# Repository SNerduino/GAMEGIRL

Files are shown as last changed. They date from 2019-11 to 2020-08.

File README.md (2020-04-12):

# GAMEGIRL
## Introduction
A very simple Game console for girls based on arduino Nano.

The console features :
- 4 color buttons with 4 color leds
- A 16X2 LCD screen for displaying menu and game information
- A Buzzer for music
- An On/Off switch
- A 9V battery as power source

For this version, the console has the form of a heat. I created it for my little daughter. Feel free to rebuild it with your own form and code your own games.

The console has a game registration mechanism, a Highscore saving in EEPROM, and integrates my RTTTL Music playing library (that you can find in my other repository) with the possibility of multitasking led animation (using PMW) with button reading screen updates and audio playing.

## GAMEGIRL RECIPE
### General recipe
To build a GAMEGIRL, you need :
- A shell (be creative)
- Buttons
- LEDS
- An arduino board (we prefer using the little ones like the arduino nano)
- An i2C LCD screen (can be graphical or just character based, it depends on the kind of games you are building)
- A Buzzer to make some noise
- A 9V battery + 9V battery connector + A On/Off switch
- Wires (Lot of wires)
- Software to pilot all of this

## GAMEGIRL V 1.0 recipe
GAMEGIRL V1.0 is a simple leds/buttons game with 4leds and 4buttons as well as an alphanumeric 16X2 screen to show score, live and stuff as well as select games and view highscores.

To build it, here is what you need to do:
0. 3D print the parts froml the STL files
1. Use a hot glue to glue the i2C LCD screen inside the heart position
2. Insert the buttons and the leds in the holes (maybe you need to use a solder tool to widen the holes if the leds don't fit). The pattern is from left to right : red, yellow, green, blue.
3. Connect all ground legs of the buttons together as well as the cathodes of the leds and add a 250Ohms resistor before the ground.  
4. Glue the Arduino nano at the upper-right side of the heart
5. Solder all leds and buttons to the arduino nano pins D2 to D9:
    1. D2 -> red button
    2. D3 -> red led
    3. D4 -> yellow button
    4. D5 -> yellow led
    5. D6 -> green button
    6. D7 -> green led
    7. D8 -> blue button
    8. D9 -> blue led
6. Solder the ground to the arduino ground
7. Connect the arduino SDA/SCL (A4/A5) of I2C to the corresponding pins on the I2C LCD.
8. Connect Vcc pin of the 9V battery connector to the VIN pin of the arduino nano.
9. Connect the GND pin of the 9V battery connector to the GNG pin of the arduino nano.
10. Cut the VCC line of the barrery wire and solder the ON/OFF Switch.
11. Glue the buzzer to the top right part of the heart.
12. Solder one of the buzzer legs to the D11 pin and the other one to the GND. You may want to add a potentiometer between the leg and ground to control volume.

13. Glue the back model to the bottom part of the shell after passing the battery connector inside.
14. Connect the battery.
15. Glue the bottom part of the shell with the top part.
16. Be free to stick decorations on the console.
17. Connect the USB connector to the console
18. Use Arduino IDE to load the code GAME_GIRL.ino to the arduino nano.
19. Have fun and try to maximize your scores.

## Some photos
Here are different components installed into the top part of the console:

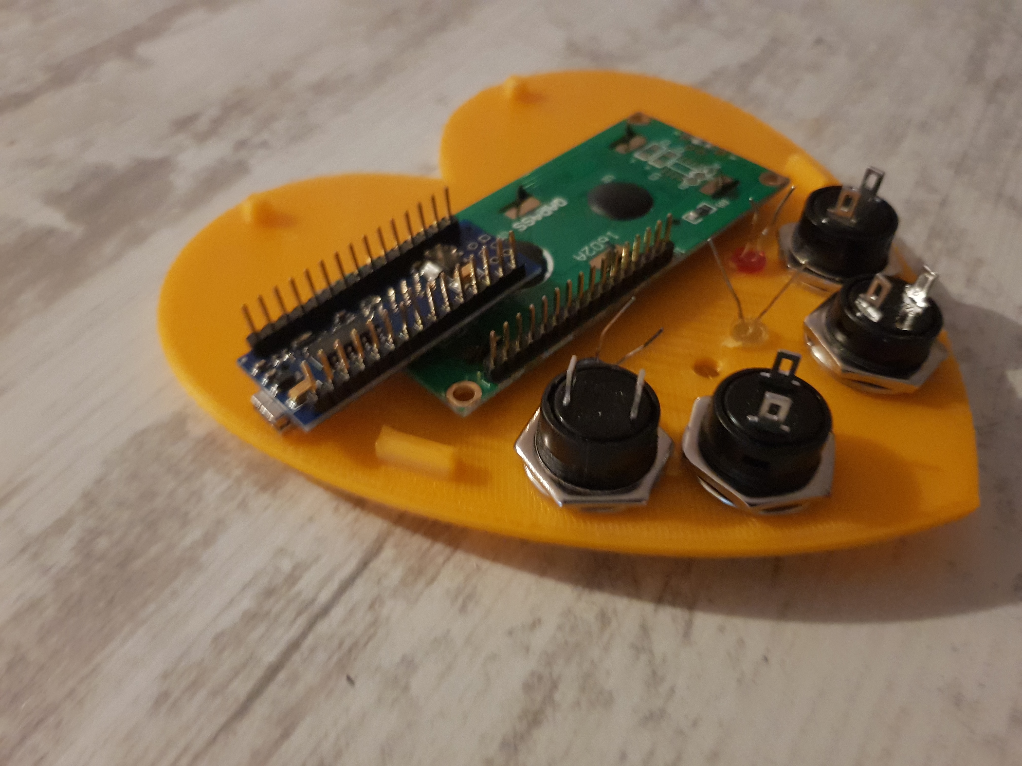
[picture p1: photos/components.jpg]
back

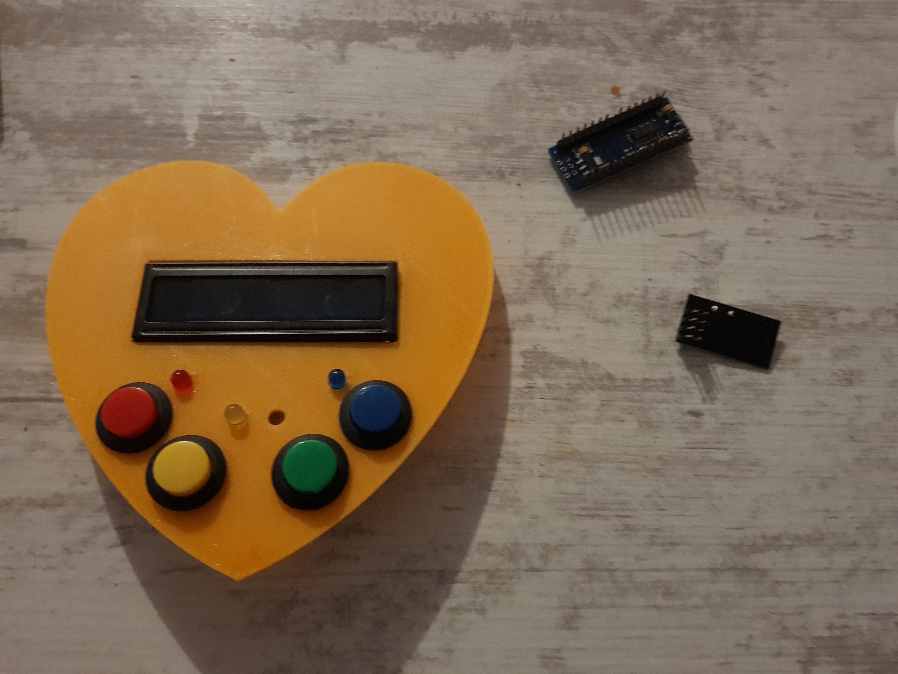
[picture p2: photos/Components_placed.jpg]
front


And here is the final product:

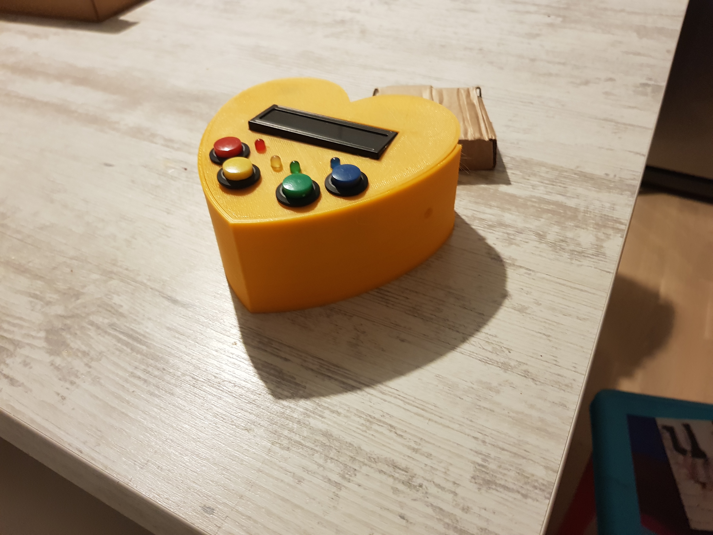
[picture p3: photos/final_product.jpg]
final product


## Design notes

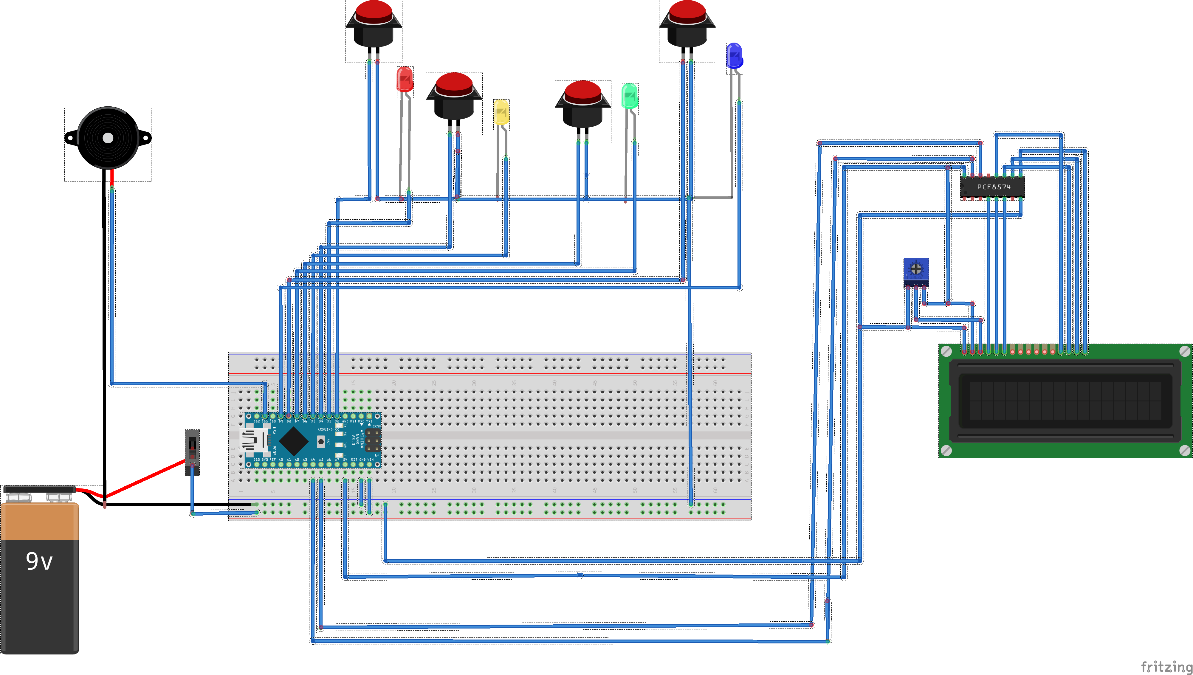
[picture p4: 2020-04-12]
Scheme/GameGirl_bb.png

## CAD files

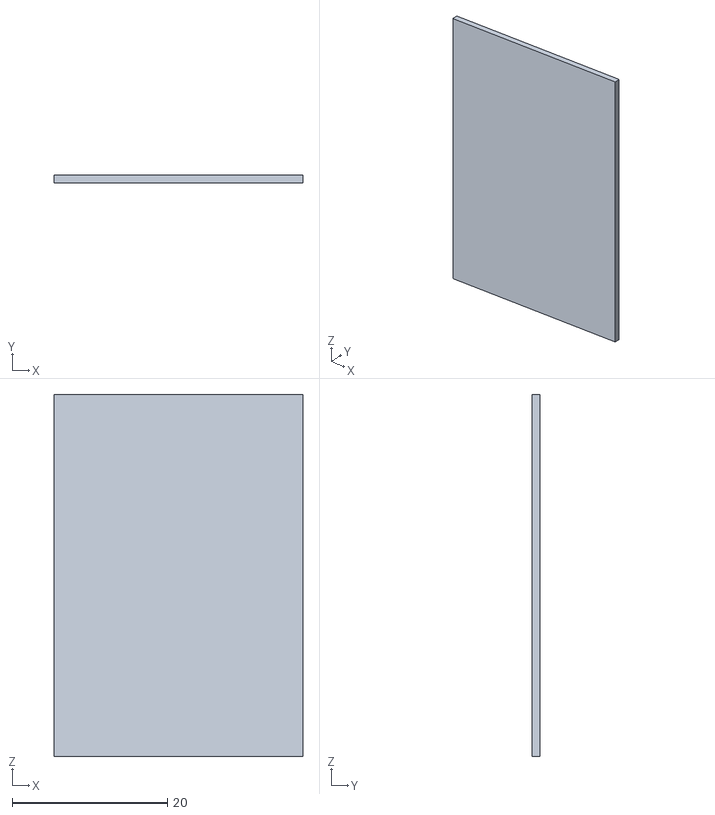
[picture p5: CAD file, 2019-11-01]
Mecanic/Back.stl
32.0 x 1.00 x 46.6

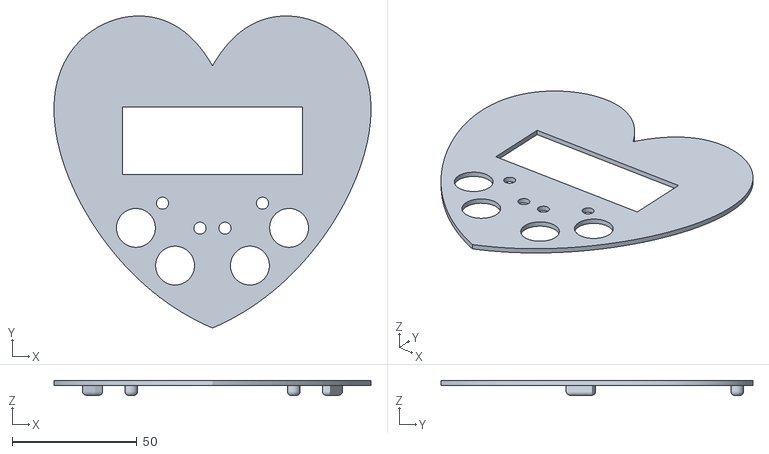
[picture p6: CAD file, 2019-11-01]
Mecanic/Boitier_Top.stl
127.0 x 125.0 x 6.00

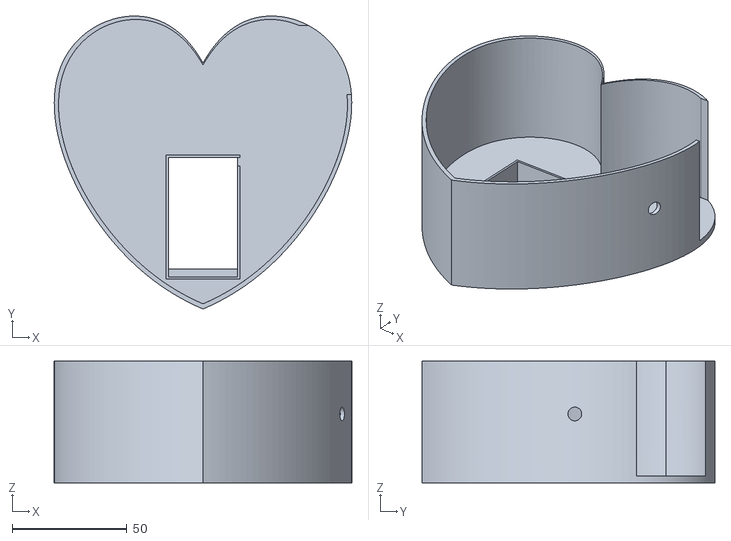
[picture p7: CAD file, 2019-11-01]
Mecanic/Boitier_Bottom.stl
129.5 x 127.5 x 53.0

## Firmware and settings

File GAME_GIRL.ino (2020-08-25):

// GAMEGIRL
// Author: Saifeddine ALOUI AKA SNetuino
// With the help from Line ALOUI

// Import libraries
#include <RTTTL.h>
#include <Wire.h>
#include <LiquidCrystal_I2C.h>
#include <EEPROM.h>

// ===========================
// Defines
// ===========================
// prepare software
#if defined(ARDUINO) && ARDUINO >= 100
#define printByte(args)  write(args);
#else
#define printByte(args)  print(args,BYTE);
#endif
#define NB_MAX_HIGH_SCORES 5


// ===========================
// Enums
// ===========================

// Game parameters
typedef enum {
  status_menu,
  status_playing,
  status_gameover
} System_Status;


// ===========================
// Structures
// ===========================
struct Game { // Every game has an instance from this structure that defines the game name and the function to call to launch the game
  char* name;
  void (*fn)(void);
};

struct ScoreInfo { // Score information (each highscore is composed of the value of the score and the name (3 chars + 0)
  int score;
  char name[4];
};

struct HighScores { // This structure will be flashed to the EEPROM to save high scores
  int hash;
  ScoreInfo scores[NB_MAX_HIGH_SCORES]; //
};

// ===========================
// global variables
// ===========================
// *** High scores ***
int eeAddress = 0; // Address to put highscore data on the EEPROM
HighScores highScores; // highscores structure to save on the EEPROM

// *** Games definition ***
// Games functions prototypes
void reflex_tester(); // A game to test reflexes
void color_memory(); // A game to test capacity to memorize colors sequences
void play_intro(); // Plays intro song
void sticks(); // A sticks removal game
void display_highscores(); // A code to show the savced highscores

Game games[] = { // Here we define games. Add your own games
  {.name = "Reaction test", .fn = reflex_tester},
  {.name = "Color memory", .fn = color_memory},
  {.name = "Sticks", .fn = sticks},
  {.name = "Play Song", .fn = play_intro},
  {.name = "High scores", .fn = display_highscores}
};
int nb_games = sizeof(games) / sizeof(Game); // Computes the number of games
int game_id = 0; // Currently selected game index
int high_score_id = 0; // Current high score index

// *** Global gaming status ***
System_Status system_status = status_menu; // 0 => Menu, 1=> Playing, 2=> Game over

// *** Hardware variables ***
// Prepare liquid crystal
LiquidCrystal_I2C lcd(0x27, 16, 2); // set the LCD address to 0x27 for a 16 chars and 2 line display_infos
// Define a heart needed to show how many lives left
uint8_t heart[8] = {0x0, 0xa, 0x1f, 0x1f, 0xe, 0x4, 0x0};

// -- Pins --
// Buttons and leds connected on D2 to D9 button led, button led...
int btn_red = 2;
int led_red = 3;
int btn_yellow = 4;
int led_yellow = 5;
int btn_green = 6;
int led_green = 7;
int btn_blue = 8;
int led_blue = 9;

// An array of buttons and leds (useful to games that use color indexing)
int btns_list[] = {btn_red, btn_yellow, btn_green, btn_blue};
int leds_list[] = {led_red, led_yellow, led_green, led_blue};

// -- Buzzer --
int audio_out = 11;


// *** Audio music ***
// Instantiate the RTTTL object
RTTTL rtttl = RTTTL(audio_out);

// -- Music and sound effects ---
char intro[] = "smb:d=4,o=5,b=100:16e6,16e6,32p,8e6,16c6,8e6,8g6,8p,8g,8p,8c6,16p,8g,16p,8e,16p,8a,8b,16a#,8a,16g.,16e6,16g6,8a6,16f6,8g6,8e6,16c6,16d6,8b,16p,8c6,16p,8g,16p,8e,16p,8a,8b,16a#,8a,16g.,16e6,16g6,8a6,16f6,8g6,8e6,16c6,16d6,8b,8p,16g6,16f#6,16f6,16d#6,16p,16e6,16p,16g#,16a,16c6,16p,16a,16c6,16d6,8p,16g6,16f#6,16f6,16d#6,16p,16e6,16p,16c7,16p,16c7,16c7,p,16g6,16f#6,16f6,16d#6,16p,16e6,16p,16g#,16a,16c6,16p,16a,16c6,16d6,8p,16d#6,8p,16d6,8p,16c6";
char Ready[] = "rd:d=4,o=5,b=355:16a6"; // Ready
// Buttons sound effects
char m_red[] = "rd:d=4,o=5,b=355:16c6";
char m_yellow[] = "rd:d=4,o=5,b=355:16d6";
char m_green[] = "rd:d=4,o=5,b=355:16e6";
char m_blue[] = "rd:d=4,o=5,b=355:16f6";

// Sound effefcts for good and bad responses
char OK[] = "smb:d=4,o=5,b=100:16c6,16a6";
char KO[] = "smb:d=4,o=5,b=100:16a6,16c6";

// Game over music
char m_game_over[] = "gameover:d=4,o=4,b=200:8c5,4p,8g4,4p,4e4,6a4,6b4,6a4,6g#4,6a#4,6g#4,4g4,4f4,2g4";

// List of button sound effectus to simplify indexing
char * audio_list[] = {m_red, m_yellow, m_green, m_blue};


// *** Gaming information ***
int level = 0; // Current level
int score = 0; // Current score
int lives = 3; // Number of lives


// *** Specific games variables ***
// Reflex tester params
int current_color = 0;

// Color memory params
int mem_buffer[10];  // A buffer containing the sequence of colors to do
int memory_status = 0; // Current position of the pressed


// ===========================
// Helper functions
// ===========================
// -- EEPROM read/write --
// Loads scores from EEPROM
void load_scores()
{
  EEPROM.get(eeAddress, highScores);
  if (highScores.hash != 0x5A1F)
  {
    for (int i = 0; i < 5; i++)
    {
      highScores.scores[i].score = 0;
      highScores.scores[i].name[0] = 0;
      highScores.scores[i].name[1] = 0;
      highScores.scores[i].name[2] = 0;
      highScores.scores[i].name[3] = 0;
    }
    highScores.hash = 0x5A1F;
    EEPROM.put(eeAddress, highScores);
  }
}

// -- LED --
// Drive leds using software PWM
// param pin  : Led pin
// param ampl : Amplitude of light (0 -> 255)
// duration : This function blocks for duration milliseconds
void soft_pwm(int pin, int ampl, int duration)
{
  for (int i = 0; i < duration; i++)
  {
    digitalWrite(pin, HIGH);
    delayMicroseconds(ampl); // Approximately 10% duty cycle @ 1KHz
    digitalWrite(pin, LOW);
    delayMicroseconds(1000 - ampl);
  }
}

// Drive leds using software PWM while playing an audio
// param pin  : Led pin
// param ampl : Amplitude of light (0 -> 255)
// max_duration : This function blocks for duration milliseconds at max. If audio finishes first, this function returns
// audio : The audio to be played (RTTTL string)
//
void soft_pwm_withaudio(int pin, int ampl, int max_duration, char *audio)
{
  rtttl.playMelody(audio);
  int i = 0;
  while (i < max_duration && max_duration > 0 || rtttl.m_currentNote.info != RTTTL_INFO_EOM)
  {
    digitalWrite(pin, HIGH);
    delayMicroseconds(ampl); // Approximately 10% duty cycle @ 1KHz
    digitalWrite(pin, LOW);
    delayMicroseconds(1000 - ampl);
    rtttl.tick();
    i++;
  }
}

void reset()
{
  level = 0;
  score = 0;
  lives = 3;
}

// -- Main menu --
// Updates main menu interface
void update_menu()
{
  lcd.clear();
  lcd.setCursor(1, 0);
  lcd.print(games[game_id].name);
  if (game_id + 1 < nb_games)
  {
    lcd.setCursor(1, 1);
    lcd.print(games[game_id + 1].name);
  }
  lcd.setCursor(0, 0);
  lcd.print(">");
}
// Displays and manages main menu and games launching system
void display_menu()
{
  int validated = false;
  update_menu();

  while (!validated)
  {
    if (!digitalRead(btn_blue))
    {
      game_id -= 1;
      if (game_id == -1)
      {
        game_id = nb_games - 1;
      }
      update_menu();
      soft_pwm_withaudio(led_blue, 50, 200, m_blue);
    }
    if (!digitalRead(btn_green))
    {
      game_id += 1;
      if (game_id == nb_games)
      {
        game_id = 0;
      }
      update_menu();

      soft_pwm_withaudio(led_green, 50, 200, m_green);
    }
    if (!digitalRead(btn_yellow))
    {
      validated = true;
      system_status = status_playing;
      reset();
      update_menu();
      soft_pwm_withaudio(led_yellow, 100, 200, m_yellow);
      display_infos();
      delay(1000);
    }
  }
}
// -- HighScores --
// Updates highscore LCD UI
void update_highscore()
{
  lcd.clear();
  lcd.setCursor(1, 0);
  lcd.print(high_score_id);
  lcd.print(" : ");
  lcd.print(highScores.scores[high_score_id].name);
  lcd.print(" : ");
  lcd.print(highScores.scores[high_score_id].score);
  if (high_score_id + 1 < NB_MAX_HIGH_SCORES)
  {
    lcd.setCursor(1, 1);
    lcd.print(high_score_id + 1);
    lcd.print(" : ");
    lcd.print(highScores.scores[high_score_id + 1].name);
    lcd.print(" : ");
    lcd.print(highScores.scores[high_score_id + 1].score);
  }
  lcd.setCursor(0, 0);
}
// Lisplay and manage highscores list
void display_highscores()
{
  int validated = false;
  high_score_id = 0;
  update_highscore();

  while (!validated)
  {
    if (!digitalRead(btn_blue))
    {
      high_score_id -= 1;
      if (high_score_id == -1)
      {
        high_score_id = NB_MAX_HIGH_SCORES - 1;
      }
      update_highscore();
      soft_pwm_withaudio(led_blue, 50, 200, m_blue);
    }
    if (!digitalRead(btn_green))
    {
      high_score_id += 1;
      if (high_score_id == NB_MAX_HIGH_SCORES)
      {
        high_score_id = 0;
      }
      update_highscore();

      soft_pwm_withaudio(led_green, 50, 200, m_green);
    }
    if (!digitalRead(btn_yellow))
    {
      validated = true;
      system_status = status_menu;
      reset();
      update_highscore();
      soft_pwm_withaudio(led_yellow, 100, 200, m_yellow);
      update_highscore();
      delay(1000);
    }
  }
}

// -- Gameover --
// Show current highscore
void show_high_score(int id, int current_idx)
{
  lcd.clear();
  lcd.print("High score :");
  lcd.print(id + 1);
  lcd.setCursor(4, 1);
  lcd.print(":");
  lcd.print(score);
  for (int char_id = 0; char_id <= current_idx; char_id++)
  {
    lcd.setCursor(char_id, 1);
    lcd.print(highScores.scores[id].name[char_id]);
  }
}
// Galme is over UI
void game_over()
{
  bool get_out = false;
  lcd.clear();
  lcd.setCursor(3, 0);
  lcd.print("GAME OVER");
  lcd.setCursor(0, 1);
  lcd.print("score :");
  lcd.print(score);
  play_melody_with_leds(50, m_game_over);
  // show scores
  for (int i = 0; i < NB_MAX_HIGH_SCORES; i++)
  {
    if (score > highScores.scores[i].score)
    {
      for (int j = 4; j >= i + 1; j--)
      {
        highScores.scores[j].score = highScores.scores[j - 1].score;
        highScores.scores[j].name[0] = highScores.scores[j - 1].name[0];
        highScores.scores[j].name[1] = highScores.scores[j - 1].name[1];
        highScores.scores[j].name[2] = highScores.scores[j - 1].name[2];
      }


      highScores.scores[i].score = score;
      get_out = false;
      int char_id = 0;
      highScores.scores[i].name[char_id] = 'A';
      show_high_score(i , char_id);
      while (!get_out)
      {
        if (!digitalRead(btn_blue))
        {
          highScores.scores[i].name[char_id] -= 1;
          if (highScores.scores[i].name[char_id] < 'A')
            highScores.scores[i].name[char_id] = 'Z';
          show_high_score(i , char_id);
          soft_pwm_withaudio(led_blue, 50, 200, m_blue);
        }
        if (!digitalRead(btn_green))
        {
          highScores.scores[i].name[char_id] += 1;
          if (highScores.scores[i].name[char_id] > 'Z')
            highScores.scores[i].name[char_id] = 'A';
          show_high_score(i , char_id);
          soft_pwm_withaudio(led_green, 50, 200, m_green);
        }

        if (!digitalRead(btn_yellow))
        {
          char_id ++;
          if (char_id == 3)
          {
            get_out = true;
            highScores.scores[i].name[char_id] = 0;
            EEPROM.put(eeAddress, highScores);
          }
          else
          {
            highScores.scores[i].name[char_id] = 'A';
          }
          show_high_score(i , char_id);
          soft_pwm_withaudio(led_yellow, 50, 200, m_yellow);
        }

      }
      break;
    }
  }
  // wait for choice
  get_out = false;
  while (!get_out)
  {
    if (!digitalRead(btn_yellow))
    {
      get_out = true;
      system_status = status_menu;
      delay(200);
    }
    if (!digitalRead(btn_red))
    {
      get_out = true;
      reset();
      system_status = status_playing;
      display_infos();
      delay(200);
    }
  }
}

// -- Useful UI --
// Display useful information (Score + Lives)
void display_infos()
{
  lcd.clear();
  lcd.setCursor(0, 0);
  lcd.print("score :");
  lcd.print(score);
  lcd.setCursor(0, 1);
  lcd.print("Lives :");
  for (int i = 0; i < lives; i++)
    lcd.printByte(3);
}
// Display OK
void display_ok()
{
  lcd.clear();
  lcd.setCursor(0, 0);
  lcd.print(":)");
  lcd.setCursor(0, 1);
  lcd.print("O.K.");
}
// Display KO
void display_ko()
{
  lcd.clear();
  lcd.setCursor(0, 0);
  lcd.print(":(");
  lcd.setCursor(0, 1);
  lcd.print("K.O.");
}
// Displays level up interface
void display_LEVEL_UP()
{
  lcd.clear();
  lcd.setCursor(0, 0);
  lcd.print("Level Up");
  lcd.setCursor(0, 1);
  lcd.print(level);
  delay(1000);
}

// -- Audio play --
// Plays a melody while randomly showing leds
void play_melody_with_leds(int led_ampl, char* melody)
{
  rtttl.playMelody(melody, false);
  int led_id = random(4);
  int hold = false;
  int current_note = 0;
  while ( rtttl.m_currentNote.info != RTTTL_INFO_EOM )
  {
    rtttl.tick();
    if (!hold)
      digitalWrite(leds_list[led_id], HIGH);
    delayMicroseconds(led_ampl); // Approximately 10% duty cycle @ 1KHz
    if (!hold)
      digitalWrite(leds_list[led_id], LOW);
    delayMicroseconds(1000 - led_ampl);
    if (current_note != rtttl.m_currentNote.note)
    {
      if (rtttl.m_currentNote.note > 0)
      {
        led_id = random(4);
        hold = false;
      }
      else
      {
        hold = true;
      }
      current_note = rtttl.m_currentNote.note;
    }
  }
}




// ===========================
// Arduino setup functions
// ===========================
// Prepare game
void setup() {
  // put your setup code here, to run once:
  pinMode(audio_out, OUTPUT);   // sets the pin as output
  Serial.begin(115200);
  lcd.init();                      // initialize the lcd
  lcd.backlight();
  pinMode(btn_red, INPUT_PULLUP);
  pinMode(led_red, OUTPUT);
  pinMode(btn_yellow, INPUT_PULLUP);
  pinMode(led_yellow, OUTPUT);
  pinMode(btn_green, INPUT_PULLUP);
  pinMode(led_green, OUTPUT);
  pinMode(btn_blue, INPUT_PULLUP);
  pinMode(led_blue, OUTPUT);
  lcd.home();
  lcd.createChar(3, heart);
  randomSeed(analogRead(0));

  // Show interface
  lcd.clear();
  lcd.setCursor(3, 0);
  lcd.print("GAME GIRL");
  delay(5);

  // Load scores
  load_scores();

  // Game menu
  display_menu();

}

// ================================
// Main Arduino loop
// ================================
void loop()
{
  int state = 0; // 0 => Menu, 1=> Playing, 2=> Game over
  switch (system_status)
  {
    case status_menu:
      display_menu();
      break;

    case status_playing:
      games[game_id].fn();
      break;

    case status_gameover:
      game_over();
      break;
  }
}


// ================================
// Games
// ================================

// ============================ Reflex tester =========================
void show_led_and_wait_reaction(int led_id, int ampl, int max_duration)
{
  bool is_out = 0;
  rtttl.playMelody(audio_list[led_id]);
  int i = 0;
  display_infos();
  while ((i < max_duration && max_duration > 0 || rtttl.m_currentNote.info != RTTTL_INFO_EOM ) && !is_out)
  {
    digitalWrite(leds_list[led_id], HIGH);
    delayMicroseconds(ampl); // Approximately 10% duty cycle @ 1KHz
    digitalWrite(leds_list[led_id], LOW);
    delayMicroseconds(1000 - ampl);
    rtttl.tick();
    i++;

    for (int j = 0; j < 4; j++)
    {
      if (!digitalRead(btns_list[j]))
      {
        if (led_id == j)
        {
          score += 1;
          Serial.println("DATA:4");
          soft_pwm_withaudio(leds_list[j], ampl, 0, OK);
        }
        else
        {
          lives--;
          soft_pwm_withaudio(leds_list[j], ampl, 0, KO);
        }
        display_infos();
        is_out = true;
      }
    }
  }
  if (i >= max_duration && max_duration > 0)
  {
    lives--;
    soft_pwm_withaudio(leds_list[i], ampl, 0, KO);
  }

}

void reflex_tester() {
  current_color = random(4);
  show_led_and_wait_reaction(current_color, 50, 1000);
  if (lives == 0)
  {
    system_status = status_gameover;
  }
}



// ========================= Play Intro +++++++++++
void play_intro()
{
  play_melody_with_leds(50, intro);
}
// ========================= Sticks +++++++++++
int current_vals=21;
bool updated=false;
int player_id=1;
void switch_player()
{
  if(player_id==1)
  player_id=2;
  else
  player_id=1;
}
void sticks() {
 if(!updated)
 { 
   lcd.clear();
   lcd.setCursor(0, 0);
   lcd.print("Player :");      
   lcd.print(player_id);
   delay(2000);
   lcd.clear();
   lcd.setCursor(0, 0);
   for (int i=0;i<current_vals;i++)
   {
     if(i==16)
     {
       lcd.setCursor(0, 1);
     }     
     lcd.print("|");      
   }
   updated=true;
 }
 if (!digitalRead(btn_red))
 {
  current_vals-=1;
  soft_pwm_withaudio(led_red, 100, 1000, m_red);
  switch_player();
  updated=false;
 }
 if (!digitalRead(btn_yellow))
 {
  current_vals-=2;
  soft_pwm_withaudio(led_yellow, 100, 1000, m_yellow);
  switch_player();
  updated=false;  
 }
 if (!digitalRead(btn_green))
 {
  current_vals-=3;
  soft_pwm_withaudio(led_green, 100, 1000, m_green);
  switch_player();
  updated=false;
 }
 if (!digitalRead(btn_blue))
 {
  current_vals-=4;
  soft_pwm_withaudio(led_blue, 100, 1000, m_blue);
  switch_player();
  updated=false;
 }
 if (current_vals<=1)
 {
  current_vals=21;
   lcd.clear();
   lcd.setCursor(0, 0);
   lcd.print("Player :");      
   lcd.print(player_id);
   lcd.print(" Won");
   delay(2000);
  
  system_status = status_menu;  
  updated=false;
 }

}
// ========================= Color MEMORY +++++++++++
// Generate colors sequence
void generate_sequence()
{
  for (int i = 0; i < level + 3; i++)
    mem_buffer[i] = random(4) + 1;
}
// Main game function for Color Memory
void color_memory() {
  switch (memory_status)
  {
    case 0:
      generate_sequence();
      memory_status = 1;
      break;
    case 1: // Affichage des couleurs
      for (int i = 0; i < 3 + level; i++)
      {
        switch (mem_buffer[i])
        {
          case 1:
            lcd.clear();
            lcd.setCursor(1, 0);
            lcd.print("Red");
            soft_pwm_withaudio(led_red, 100, 1000, m_red);
            break;
          case 2:
            lcd.clear();
            lcd.setCursor(1, 0);
            lcd.print("Yellow");
            soft_pwm_withaudio(led_yellow, 100, 1000, m_yellow);
            break;
          case 3:
            lcd.clear();
            lcd.setCursor(1, 0);
            lcd.print("Green");
            soft_pwm_withaudio(led_green, 50, 1000, m_green);
            break;
          case 4:
            lcd.clear();
            lcd.setCursor(1, 0);
            lcd.print("Blue");
            soft_pwm_withaudio(led_blue, 50, 1000, m_blue);
            break;
        }
      }
      current_color = 0;
      memory_status = 2;
      display_infos();
      break;
    case 2: // Attente de réaction utilisateur
      if (!digitalRead(btn_red))
      {
        if (mem_buffer[current_color] == 1)
        {
          display_ok();
          current_color ++;
          Serial.println("DATA:1");
          soft_pwm_withaudio(led_red, 100, 0, OK);
        }
        else
        {
          display_ko();
          lives--;
          rtttl.playMelody(KO, false, true);
          memory_status = 0;
        }
        display_infos();
      }
      if (!digitalRead(btn_yellow))
      {
        if (mem_buffer[current_color] == 2)
        {
          display_ok();
          current_color ++;
          Serial.println("DATA:2");
          soft_pwm_withaudio(led_yellow, 100, 0, OK);
        }
        else
        {
          display_ko();
          lives--;
          rtttl.playMelody(KO, false, true);
          memory_status = 0;
        }
        display_infos();
      }
      if (!digitalRead(btn_green))
      {
        if (mem_buffer[current_color] == 3)
        {
          display_ok();
          current_color ++;
          Serial.println("DATA:3");
          soft_pwm_withaudio(led_green, 50, 0, OK);
        }
        else
        {
          display_ko();
          lives--;
          rtttl.playMelody(KO, false, true);
          memory_status = 0;
        }
        display_infos();
      }
      if (!digitalRead(btn_blue))
      {
        if (mem_buffer[current_color] == 4)
        {
          display_ok();
          current_color ++;
          Serial.println("DATA:4");
          soft_pwm_withaudio(led_blue, 50, 0, OK);
        }
        else
        {
          display_ko();
          lives--;
          rtttl.playMelody(KO, false, true);
          memory_status = 0;
        }
        display_infos();
      }
      if (current_color == level + 3)
      {
        score ++;
        if (score % 5 == 0)
        {
          level++;
          display_LEVEL_UP();
        }
        memory_status = 0;
        display_infos();
      }

      break;
  }
  if (lives == 0)
  {
    system_status = status_gameover;
  }
}

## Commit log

2019-11-01 Added a GAMEGIRL Recipe Added STL models to build the outside part
    [Back.stl, Boitier_Bottom.stl, Boitier_Top.stl]
2020-04-12 Added Schemes
    [GameGirl.fzz]
2020-04-12 Upgraded images
    [GameGirl.fzz]
2020-04-12 Upgraded fritzing file
    [GameGirl.fzz]
